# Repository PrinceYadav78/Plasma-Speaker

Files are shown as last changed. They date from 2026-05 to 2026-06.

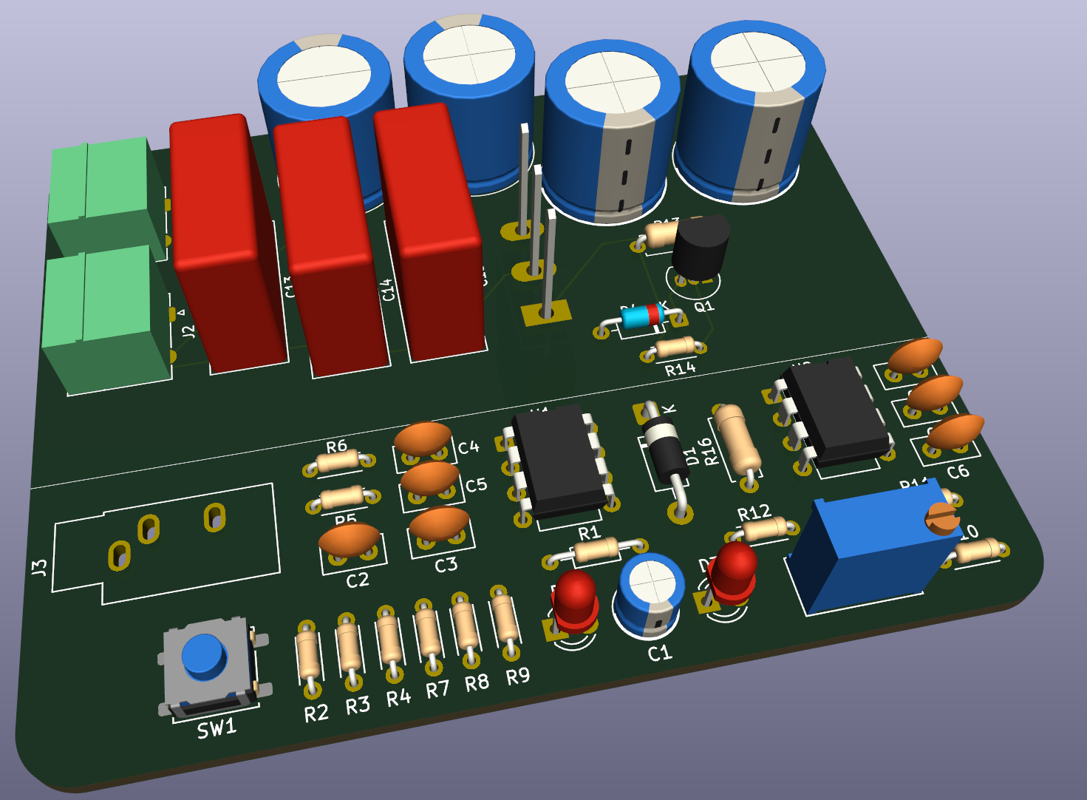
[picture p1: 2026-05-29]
Images/Screenshot 2026-05-18 182442.png

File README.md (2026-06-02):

# Plasma Speaker – PCB Design

so this is my plasma speaker project which i made for my college physics project. basically designed the full circuit and pcb myself from scratch, took around 6 days total. hope it comes out good when i actually build it lol

---

## Why I Did This

honestly it started just as a college physics submission but then i got genuinely interested in how it actually works. plasma speakers are cool because theres no physical cone or membrane, sound comes directly from ionised air through a high voltage arc. felt way more interesting than doing some boring experiment so i decided to design the full electronics myself instead of just buying something readymade

---

## How I Did It

split the whole thing into 4 sections, each one feeds into the next

**DC Input Stage**
started here becuase i wanted stable power before touching anything else. 24v input goes down to 12v using a 1N4742 zener diode with 330ohm 1w resistor. added 100uf smoothing cap and a led indicator. was originally thinking of using 7812 regulator but the heat dissipation at 24v input looked annoying so switched to zener setup. forgot cap polarity once and had to recheck 💀

**Power Switching Stage**
this is the main section, handles high current switching and drives the transformer later. used IRFP260N mosfet becuase cheaper mosfets felt risky after checking other plasma speaker builds. put multiple 470uf 35v caps on the input rail for handling sudden current spikes, started with just one and added more after reading about ripple current. also mixed mkp10 film caps with electrolytics becuase film caps handle high frequency noise better, didnt actually know why people do this before this project 😭. bc327 handles gate drive. routing got messy really fast, almost connected drain and source wrong on the mosfet 💀

**Zero Cross Detector**
built around LM331N with rc filter network using 10n caps. this was genuinly the most confusing part, timing and comparator stuff is more theoretical than power electronics. spent alot of time just reading the datasheet and looking at application circuits. got confused between feedback path and threshold pin like 3 times. still not fully sure it will behave exactly how i want until i test it on oscilloscope honestly

**Oscillator**
NE555 in astable mode. choosed 555 becuase its simple and well documented, didnt want to deal with complicated pwm ic on top of everything else. 10n and 4.7n timing caps with 5k pot for manual frequency adjustment because transformer resonance can vary and i wanted tuning option during testing. almost connected discharge pin wrong aswell 💀 led indicator added to atleast visually confirm its running

---

## PCB Design

did this in kicad didnt really have a big plan going in, just placed things with few things in mind

- terminal connectors and aux stuff on one side, big caps on the other side
- power section components as close as possible to keep traces short
- mosfet placed face down so i can attach aluminium block behind for cooling
- lm331 and ne555 grouped together on bottom half of board
- copper zones filled on both layers for cooling and reducing noise

did silkscreen on both front and back copper layers, took quite some time but looks nice. only real rule i followed was keep connections short and make it look atleast a little symmetric

---

## Components

sourced everything from mouser, made full bom and verified all parts. cart is ready

---

## Build Log

| Day | What I did | Time |
|-----|---|---|
| 1 | DC input stage schematic | 30min |
| 2 | Power switching stage schematic | 2hr 30min |
| 3 | Zero cross detector schematic | 3hr |
| 4 | Oscillator schematic | 2hr 45min |
| 5 | Full PCB routing and silkscreen | 4hr 30min |
| 6 | BOM and mouser sourcing and later cost cutting by switching to digikey | 1hr 30 min|

---

## Schematic



---

## PCB








---

## Cart










---

## BOM

| Index | Qty | Part Number | Manufacturer Part Number | Description | Available | Backorder | Unit Price | Extended Price INR |
|---:|----:|---|---|---|---:|---:|---:|---:|
| 1 | 10 | 2.2KEBK-ND | CFR-12JB-52-2K2 | RES 2.2K OHM 5% 1/6W AXIAL | 10 | 0 | 3.727 | ₹37.27 |
| 2 | 25 | 1.0KEBK-ND | CFR-12JB-52-1K | RES 1K OHM 5% 1/6W AXIAL | 25 | 0 | 3.0936 | ₹77.34 |
| 3 | 10 | 470EBK-ND | CFR-12JB-52-470R | RES 470 OHM 5% 1/6W AXIAL | 10 | 0 | 3.727 | ₹37.27 |
| 4 | 10 | 100EBK-ND | CFR-12JB-52-100R | RES 100 OHM 5% 1/6W AXIAL | 10 | 0 | 3.448 | ₹34.48 |
| 5 | 10 | 10KEBK-ND | CFR-12JB-52-10K | RES 10K OHM 5% 1/6W AXIAL | 10 | 0 | 3.634 | ₹36.34 |
| 6 | 10 | 220EBK-ND | CFR-12JB-52-220R | RES 220 OHM 5% 1/6W AXIAL | 10 | 0 | 3.727 | ₹37.27 |
| 7 | 10 | 33KEBK-ND | CFR-12JB-52-33K | RES 33K OHM 5% 1/6W AXIAL | 10 | 0 | 3.448 | ₹34.48 |
| 8 | 10 | 3.3KEBK-ND | CFR-12JB-52-3K3 | RES 3.3K OHM 5% 1/6W AXIAL | 10 | 0 | 3.448 | ₹34.48 |
| 9 | 10 | 399-6601-ND | ESK107M016AC3AA | CAP ALUM 100UF 20% 16V RADIAL TH | 10 | 0 | 10.064 | ₹100.64 |
| 10 | 10 | 445-8348-ND | FK16X7R1C106KR020 | CAP CER 10UF 16V X7R RADIAL | 10 | 0 | 28.235 | ₹282.35 |
| 11 | 10 | 445-180204-ND | FG18X7R1E105KRT00 | CAP CER 1UF 25V X7R RADIAL | 10 | 0 | 16.96 | ₹169.60 |
| 12 | 20 | 399-6086-ND | ESC477M035AH4AA | CAP ALUM 470UF 20% 35V RADIAL TH | 20 | 0 | 37.74 | ₹754.80 |
| 13 | 2 | IRFP260NPBF-ND | IRFP260NPBF | MOSFET N-CH 200V 50A TO247AC | 2 | 0 | 587.07 | ₹1,174.14 |
| 14 | 10 | WP710A10PGT-ND | WP710A10PGT | LED GREEN CLEAR T-1 T/H | 10 | 0 | 17.426 | ₹174.26 |
| 15 | 10 | 754-1606-ND | WP710A10ID | LED RED DIFFUSED T-1 T/H | 10 | 0 | 14.071 | ₹140.71 |
| 16 | 5 | CKN12301-ND | PTS636SL43 LFS | SWITCH TACTILE SPST-NO 0.05A 12V | 5 | 0 | 15.84 | ₹79.20 |
| 17 | 5 | 3296W-1-252LF-ND | 3296W-1-252LF | TRIMMER 2.5K OHM 0.5W PC PIN TOP | 5 | 0 | 224.58 | ₹1,122.90 |
| 18 | 10 | 13-CFR-25JR-52-270RCT-ND | CFR-25JR-52-270R | RES 270 OHM 5% 1/4W AXIAL | 10 | 0 | 3.262 | ₹32.62 |
| 19 | 10 | 330WCT-ND | FMP100JR-52-330R | RES 330 OHM 5% 1W AXIAL | 10 | 0 | 7.921 | ₹79.21 |
| 20 | 15 | 445-173264-1-ND | FG18X7R1H103KNT06 | CAP CER 10000PF 50V X7R RADIAL | 15 | 0 | 12.021 | ₹180.32 |
| 21 | 10 | 445-173265-1-ND | FG18X7R1H104KNT06 | CAP CER 0.1UF 50V X7R RADIAL | 10 | 0 | 12.953 | ₹129.53 |
| 22 | 10 | 445-173598-1-ND | FG28X7R1H472KNT06 | CAP CER 4700PF 50V X7R RADIAL | 10 | 0 | 12.021 | ₹120.21 |
| 23 | 15 | 1928-MKP1G031004D00KSSD-ND | MKP1G031004D00KSSD | MKP 10 0.1F 400V DC 7X14X18 PCM | 0 | 15 | 54.793 | ₹821.90 |
| 24 | 10 | 4878-BC327-40BK-ND | BC327-40BK | TRANS PNP 45V 0.8A TO-92 | 10 | 0 | 10.157 | ₹101.57 |
| 25 | 5 | LM311NNS/NOPB-ND | LM311N/NOPB | IC COMPARATOR 1 GEN PUR 8DIP | 5 | 0 | 85.73 | ₹428.65 |
| 26 | 5 | LM311NNS/NOPB-ND | LM311N/NOPB | IC COMPARATOR 1 GEN PUR 8DIP | 5 | 0 | 85.73 | ₹428.65 |
| 27 | 10 | 1N4742A-T50ACT-ND | 1N4742A-T50A | DIODE ZENER 12V 1W DO41 | 10 | 0 | 15.842 | ₹158.42 |
| 28 | 10 | 1N4148FS-ND | 1N4148 | DIODE STANDARD 100V 200MA DO35 | 10 | 0 | 5.125 | ₹51.25 |
| 29 | 10 | 102-6203-ND | TB007-508-02BE | TERMINAL BLOCK, SCREW TYPE, 5.08 | 10 | 0 | 36.995 | ₹369.95 |
| 30 | 5 | SC1852-ND | PJRAN1X1U01AUX | CONN RCA JACK MONO 3.2MM R/A | 5 | 0 | 275.83 | ₹1,379.15 |
| 31 | 1 | Power (Own Funded) | - | - | 1 | 0 | 3999 | ₹0 |
| 32 | 2 | Transformer (Own Funded) | - | - | 2 | 0 | 499 | ₹0 |
| 33 | 1 | PCB | - | - | 1 | 0 | 989 | ₹989 |
| | | | | **TOTAL** | | | | **₹9,597.96** |

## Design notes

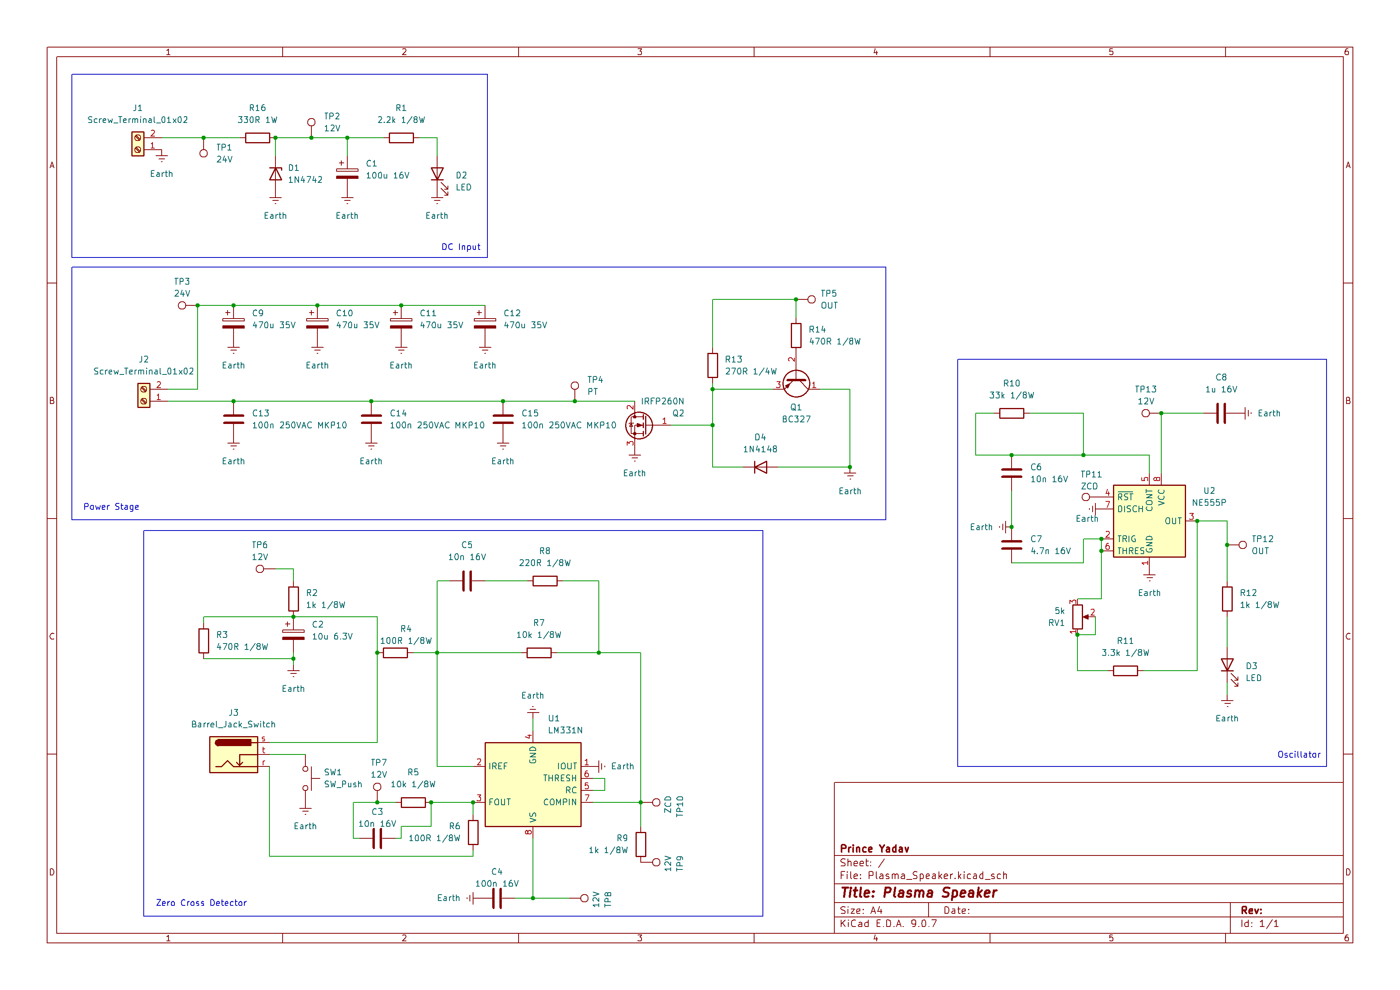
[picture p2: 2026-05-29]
Images/Schematic.png

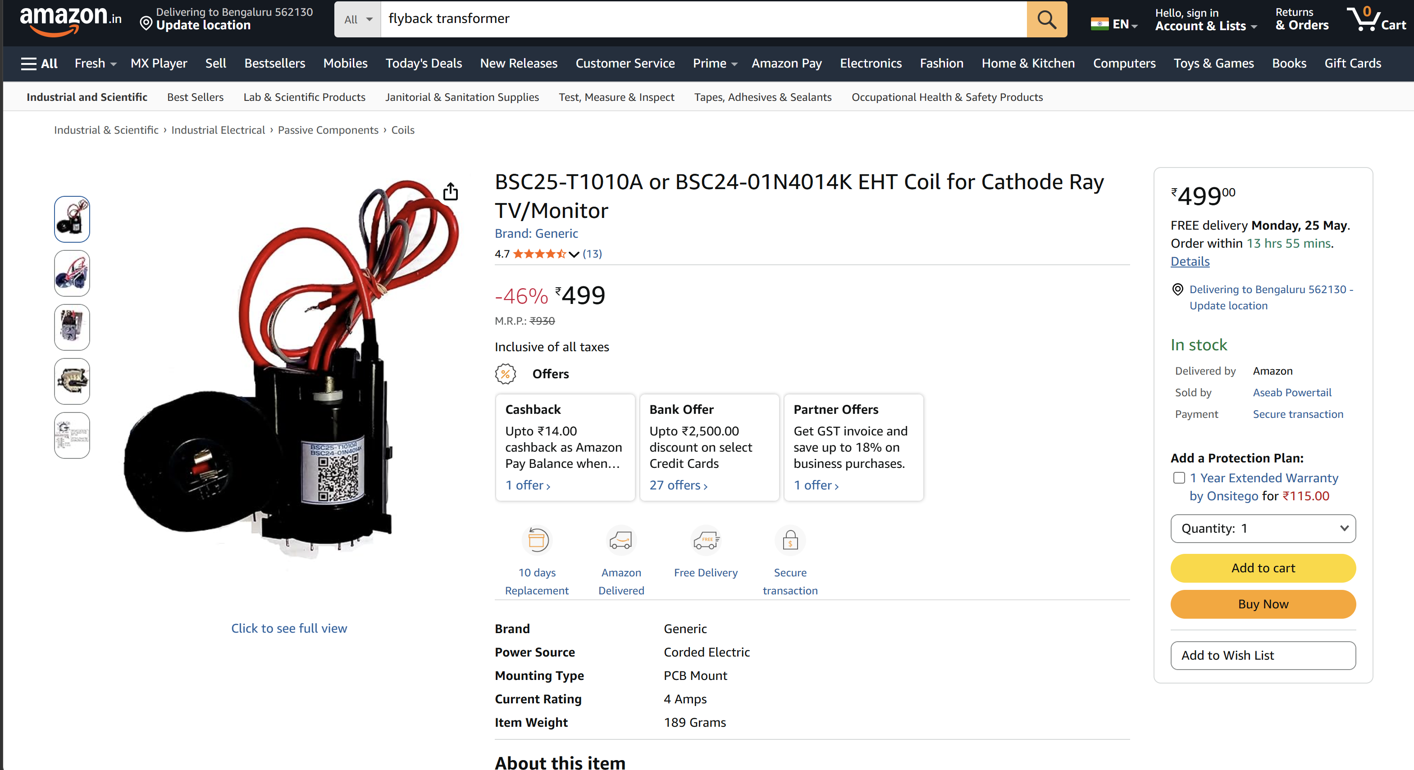
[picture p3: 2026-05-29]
Images/Screenshot 2026-05-18 190657.png

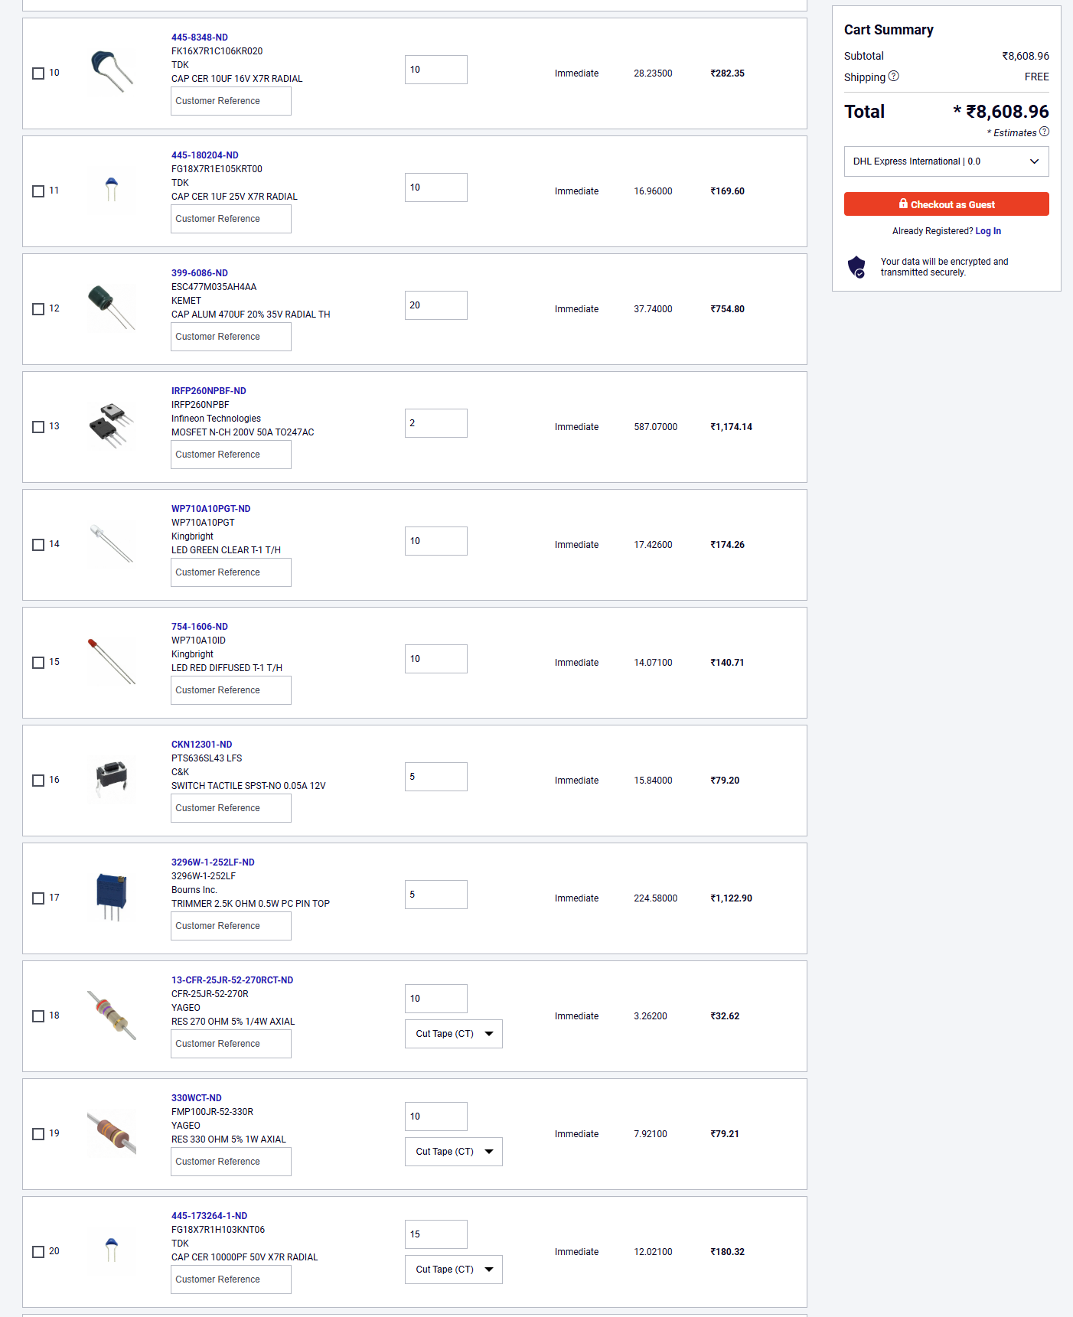
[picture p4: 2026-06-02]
Images/Screenshot 2026-06-02 192737.png

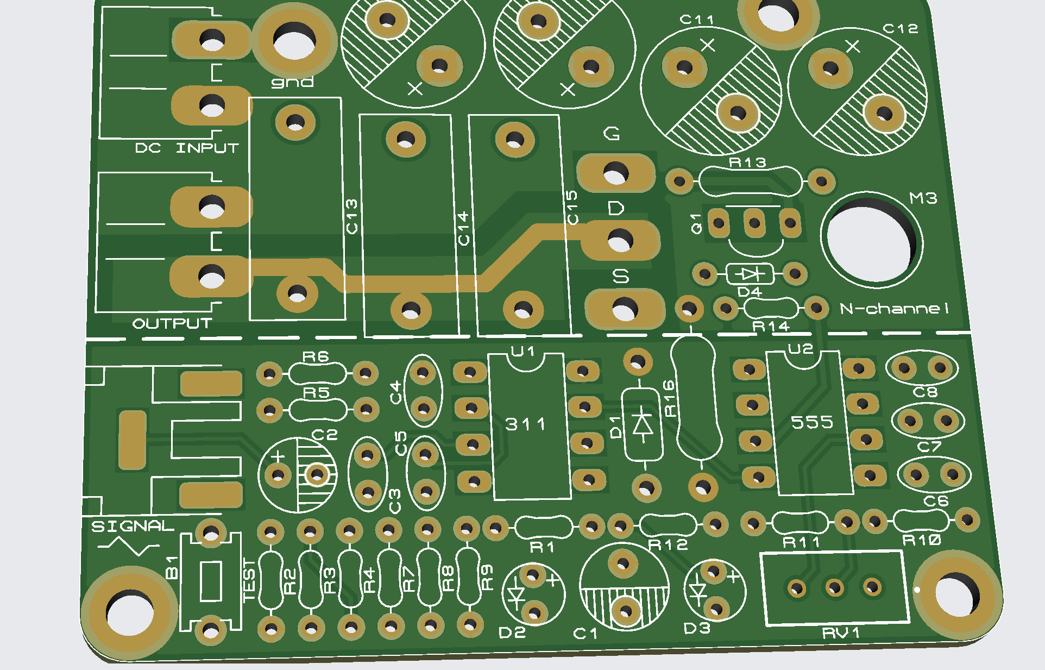
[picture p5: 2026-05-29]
Images/Screenshot 2026-05-18 182231.png

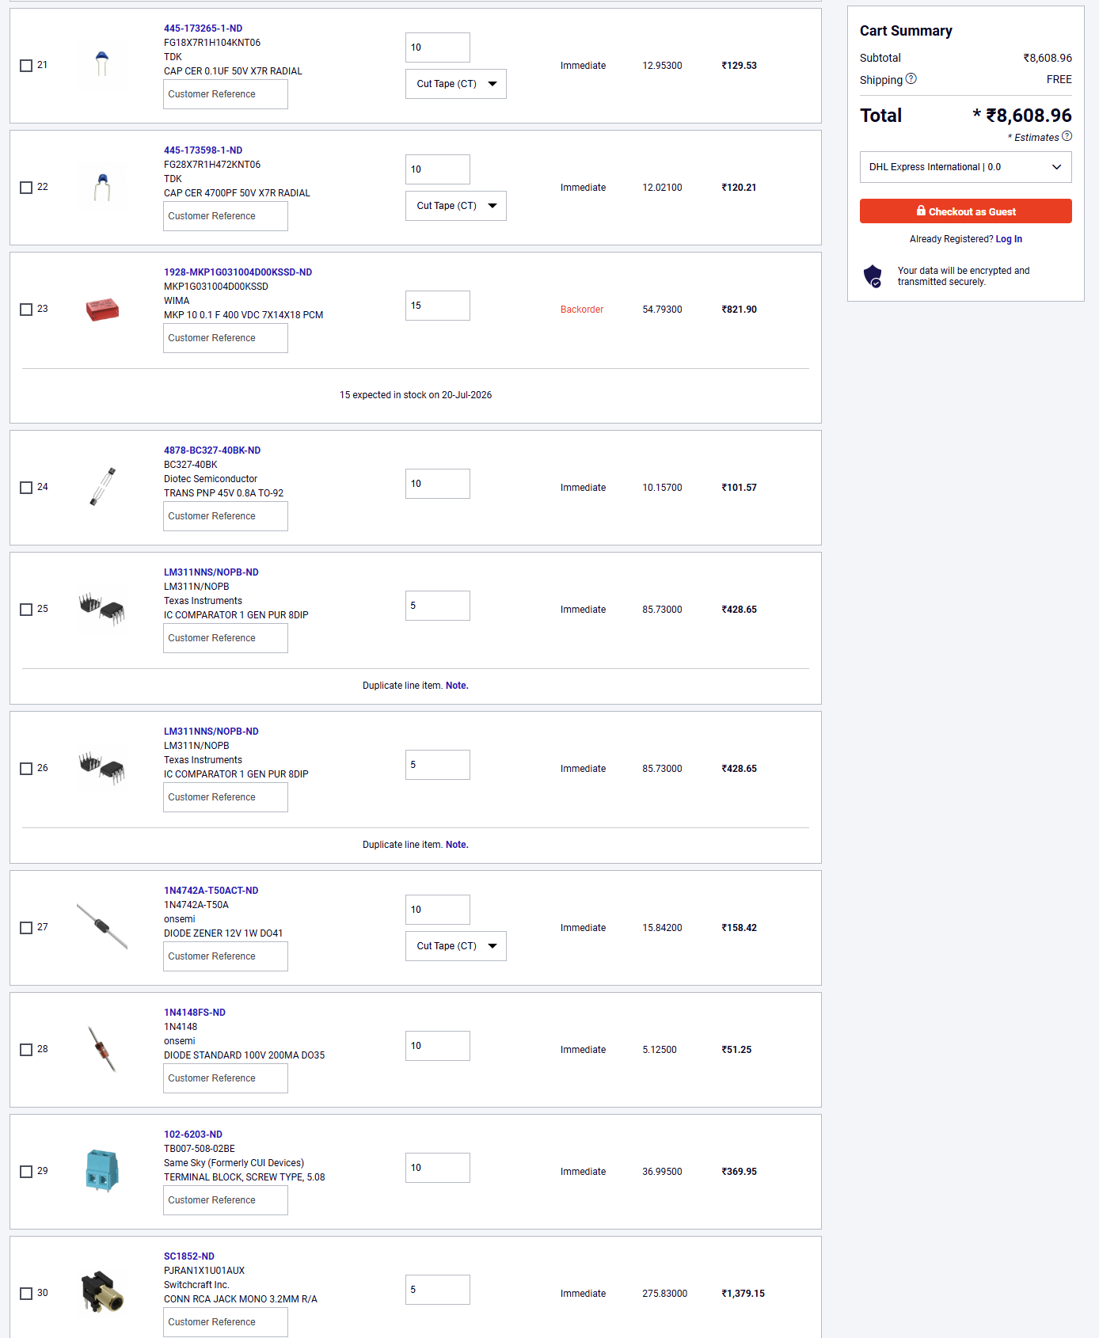
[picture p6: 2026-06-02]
Images/Screenshot 2026-06-02 192749.png

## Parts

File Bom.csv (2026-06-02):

Index | Quantity | Part Number | Manufacturer Part Number | Description | Link | Available | Backorder | Unit Price | Extended Price INR
1 | 10 | 2.2KEBK-ND | CFR-12JB-52-2K2 | RES 2.2K OHM 5% 1/6W AXIAL | https://www.digikey.in/en/products/detail/yageo/CFR-12JB-52-2K2/3992 | 10 | 0 | 3.727 | ₹37.27
2 | 25 | 1.0KEBK-ND | CFR-12JB-52-1K | RES 1K OHM 5% 1/6W AXIAL | https://www.digikey.in/en/products/detail/yageo/CFR-12JB-52-1K/4000 | 25 | 0 | 3.0936 | ₹77.34
3 | 10 | 470EBK-ND | CFR-12JB-52-470R | RES 470 OHM 5% 1/6W AXIAL | https://www.digikey.in/en/products/detail/yageo/CFR-12JB-52-470R/4005 | 10 | 0 | 3.727 | ₹37.27
4 | 10 | 100EBK-ND | CFR-12JB-52-100R | RES 100 OHM 5% 1/6W AXIAL | https://www.digikey.in/en/products/detail/yageo/CFR-12JB-52-100R/4019 | 10 | 0 | 3.448 | ₹34.48
5 | 10 | 10KEBK-ND | CFR-12JB-52-10K | RES 10K OHM 5% 1/6W AXIAL | https://www.digikey.in/en/products/detail/yageo/CFR-12JB-52-10K/3977 | 10 | 0 | 3.634 | ₹36.34
6 | 10 | 220EBK-ND | CFR-12JB-52-220R | RES 220 OHM 5% 1/6W AXIAL | https://www.digikey.in/en/products/detail/yageo/CFR-12JB-52-220R/4013 | 10 | 0 | 3.727 | ₹37.27
7 | 10 | 33KEBK-ND | CFR-12JB-52-33K | RES 33K OHM 5% 1/6W AXIAL | https://www.digikey.in/en/products/detail/yageo/CFR-12JB-52-33K/3962 | 10 | 0 | 3.448 | ₹34.48
8 | 10 | 3.3KEBK-ND | CFR-12JB-52-3K3 | RES 3.3K OHM 5% 1/6W AXIAL | https://www.digikey.in/en/products/detail/yageo/CFR-12JB-52-3K3/3989 | 10 | 0 | 3.448 | ₹34.48
9 | 10 | 399-6601-ND | ESK107M016AC3AA | CAP ALUM 100UF 20% 16V RADIAL TH | https://www.digikey.in/en/products/detail/yageo/CFR-25JR-52-270R/11960 | 10 | 0 | 10.064 | ₹100.64
10 | 10 | 445-8348-ND | FK16X7R1C106KR020 | CAP CER 10UF 16V X7R RADIAL | https://www.digikey.in/en/products/detail/yageo/FMP100JR-52-330R/2058601 | 10 | 0 | 28.235 | ₹282.35
11 | 10 | 445-180204-ND | FG18X7R1E105KRT00 | CAP CER 1UF 25V X7R RADIAL | https://www.digikey.in/en/products/detail/kemet/ESK107M016AC3AA/3083016 | 10 | 0 | 16.96 | ₹169.60
12 | 20 | 399-6086-ND | ESC477M035AH4AA | CAP ALUM 470UF 20% 35V RADIAL TH | https://www.digikey.in/en/products/detail/tdk/FK16X7R1C106KR020/2815278 | 20 | 0 | 37.74 | ₹754.80
13 | 2 | IRFP260NPBF-ND | IRFP260NPBF | MOSFET N-CH 200V 50A TO247AC | https://www.digikey.in/en/products/detail/tdk/FG18X7R1H103KNT06/5802878 | 2 | 0 | 587.07 | ₹1,174.14
14 | 10 | WP710A10PGT-ND | WP710A10PGT | LED GREEN CLEAR T-1 T/H | https://www.digikey.in/en/products/detail/tdk/FG18X7R1H104KNT06/5802879 | 10 | 0 | 17.426 | ₹174.26
15 | 10 | 754-1606-ND | WP710A10ID | LED RED DIFFUSED T-1 T/H | https://www.digikey.in/en/products/detail/tdk/FG28X7R1H472KNT06/5803212 | 10 | 0 | 14.071 | ₹140.71
16 | 5 | CKN12301-ND | PTS636SL43 LFS | SWITCH TACTILE SPST-NO 0.05A 12V | https://www.digikey.in/en/products/detail/tdk/FG18X7R1E105KRT00/7326658 | 5 | 0 | 15.84 | ₹79.20
17 | 5 | 3296W-1-252LF-ND | 3296W-1-252LF | TRIMMER 2.5K OHM 0.5W PC PIN TOP | https://www.digikey.in/en/products/detail/kemet/ESC477M035AH4AA/2712516 | 5 | 0 | 224.58 | ₹1,122.90
18 | 10 | 13-CFR-25JR-52-270RCT-ND | CFR-25JR-52-270R | RES 270 OHM 5% 1/4W AXIAL | https://www.digikey.in/en/products/detail/wima/mkp1g031004d00kssd/19251065 | 10 | 0 | 3.262 | ₹32.62
19 | 10 | 330WCT-ND | FMP100JR-52-330R | RES 330 OHM 5% 1W AXIAL | https://www.digikey.in/en/products/detail/diotec-semiconductor/bc327-40bk/13154014 | 10 | 0 | 7.921 | ₹79.21
20 | 15 | 445-173264-1-ND | FG18X7R1H103KNT06 | CAP CER 10000PF 50V X7R RADIAL | https://www.digikey.in/en/products/detail/infineon-technologies/irfp260npbf/811623 | 15 | 0 | 12.021 | ₹180.32
21 | 10 | 445-173265-1-ND | FG18X7R1H104KNT06 | CAP CER 0.1UF 50V X7R RADIAL | https://www.digikey.in/en/products/detail/texas-instruments/LM311N-NOPB/6175 | 10 | 0 | 12.953 | ₹129.53
22 | 10 | 445-173598-1-ND | FG28X7R1H472KNT06 | CAP CER 4700PF 50V X7R RADIAL | https://www.digikey.in/en/products/detail/texas-instruments/NE555P/277057 | 10 | 0 | 12.021 | ₹120.21
23 | 15 | 1928-MKP1G031004D00KSSD-ND | MKP1G031004D00KSSD | MKP 10 0.1 F 400 VDC 7X14X18 PCM | https://www.digikey.in/en/products/detail/onsemi/1N4742A-T50A/977259 | 0 | 15 | 54.793 | ₹821.90
24 | 10 | 4878-BC327-40BK-ND | BC327-40BK | TRANS PNP 45V 0.8A TO-92 | https://www.digikey.in/en/products/detail/kingbright/wp710a10pgt/3084194 | 10 | 0 | 10.157 | ₹101.57
25 | 5 | LM311NNS/NOPB-ND | LM311N/NOPB | IC COMPARATOR 1 GEN PUR 8DIP | https://www.digikey.in/en/products/detail/kingbright/WP710A10ID/2769809 | 5 | 0 | 85.73 | ₹428.65
26 | 5 | LM311NNS/NOPB-ND | LM311N/NOPB | IC COMPARATOR 1 GEN PUR 8DIP | https://www.digikey.in/en/products/detail/onsemi/1N4148/458603 | 5 | 0 | 85.73 | ₹428.65
27 | 10 | 1N4742A-T50ACT-ND | 1N4742A-T50A | DIODE ZENER 12V 1W DO41 | https://www.digikey.in/en/products/detail/c-k/PTS636SL43-LFS/10071714 | 10 | 0 | 15.842 | ₹158.42
28 | 10 | 1N4148FS-ND | 1N4148 | DIODE STANDARD 100V 200MA DO35 | https://www.digikey.in/en/products/detail/same-sky-formerly-cui-devices/tb007-508-02be/10064127 | 10 | 0 | 5.125 | ₹51.25
29 | 10 | 102-6203-ND | TB007-508-02BE | TERMINAL BLOCK, SCREW TYPE, 5.08 | https://www.digikey.in/en/products/detail/bourns-inc/3296w-1-252lf/2535912 | 10 | 0 | 36.995 | ₹369.95
30 | 5 | SC1852-ND | PJRAN1X1U01AUX | CONN RCA JACK MONO 3.2MM R/A | https://www.digikey.in/en/products/detail/switchcraft-inc/PJRAN1X1U01AUX/1288659 | 5 | 0 | 275.83 | ₹1,379.15
31 | 1 | Power ( Own Funded ) |  |  | https://www.electropi.in/24v-30amp-smps-720w-dc-metal-power-supply-nwp-india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 | 1 | 0 | 3999 | ₹0
32 | 2 | Transformer ( Own Funded ) |  |  | https://amzn.in/d/0g0eCBQw | 2 | 0 | 499 | ₹0
33 | 1 | PCB |  |  | JLCPCB | 1 | 0 | 989 | ₹989
 |  |  |  |  |  |  |  | Total | ₹9579.96 ($100)

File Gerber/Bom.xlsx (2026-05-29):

Quantity | References | Value | Code | Link | Cost | Total
5 | R1 | 2.2k | CFR-12JB-52-2K2 | CFR-12JB-52-2K2 YAGEO | Mouser India (https://www.mouser.in/ProductDetail/YAGEO/CFR-12JB-52-2K2) | ₹18.64 | ₹93.20
15 | R2,R9,R12 | 1k | CFR-12JB-52-1K | CFR-12JB-52-1K YAGEO | Mouser (https://www.mouser.com/ProductDetail/YAGEO/CFR-12JB-52-1K?qs=8uyp%2Fy7yFW6RQpJpptx%2FjA%3D%3D) | ₹8.39 | ₹125.85
10 | R3,R14 | 470R | CFR-12JB-52-470R | CFR-12JB-52-470R YAGEO | Mouser India (https://www.mouser.in/ProductDetail/YAGEO/CFR-12JB-52-470R) | ₹8.39 | ₹83.90
10 | R4,R6 | 100R | CFR-12JB-52-100R | CFR-12JB-52-100R YAGEO | Mouser India (https://www.mouser.in/ProductDetail/YAGEO/CFR-12JB-52-100R) | ₹8.39 | ₹83.90
10 | R5,R7 | 10k | CFR-12JB-52-10K | CFR-12JB-52-10K YAGEO | Mouser India (https://www.mouser.in/ProductDetail/YAGEO/CFR-12JB-52-10K) | ₹8.39 | ₹83.90
5 | R8 | 220R | CFR-12JB-52-220R | CFR-12JB-52-220R YAGEO | Mouser India (https://www.mouser.in/ProductDetail/YAGEO/CFR-12JB-52-220R) | ₹18.64 | ₹93.20
5 | R10 | 33k | CFR-12JB-52-33K | CFR-12JB-52-33K YAGEO | Mouser India (https://www.mouser.in/ProductDetail/YAGEO/CFR-12JB-52-33K) | ₹18.64 | ₹93.20
5 | R11 | 3.3k | CFR-12JB-52-3K3 | CFR-12JB-52-3K3 YAGEO | Mouser India (https://www.mouser.in/ProductDetail/YAGEO/CFR-12JB-52-3K3) | ₹18.64 | ₹93.20
5 | R13 | 270R | CFR-25JR-52-270R | CFR-25JR-52-270R YAGEO | Mouser India (https://www.mouser.in/ProductDetail/YAGEO/CFR-25JR-52-270R) | ₹9.32 | ₹46.60
5 | R16 | 330R | FMP100JR-52-330R | FMP100JR-52-330R YAGEO | Mouser India (https://www.mouser.in/ProductDetail/YAGEO/FMP100JR-52-330R) | ₹12.11 | ₹60.55
5 | C1 | 100u | ESK107M016AC3AA | ESK107M016AC3AA KEMET | Mouser India (https://www.mouser.in/ProductDetail/KEMET/ESK107M016AC3AA?qs=9RUIYXQlAdBlfkFfvuUkxQ%3D%3D) | ₹17.70 | ₹88.50
5 | C2 | 10u | FK16X7R1C106K | FK16X7R1C106K TDK | Mouser India (https://www.mouser.in/ProductDetail/TDK/FK16X7R1C106K?qs=sGAEpiMZZMvsSlwiRhF8qk5dk0Ff3GLt7CBGZPfzGBA%3D) | ₹46.59 | ₹232.95
15 | C3,C5,C6 | 10n | FG18X7R1H103KNT06 | FG18X7R1H103KNT06 TDK | Mouser India (https://www.mouser.in/ProductDetail/TDK/FG18X7R1H103KNT06) | ₹8.67 | ₹130.05
5 | C4 | 100n | FG18X7R1H104KNT06 | FG18X7R1H104KNT06 TDK | Mouser India (https://www.mouser.in/ProductDetail/TDK/FG18X7R1H104KNT06?qs=qf2ddTMq67WA8sH6FratLA%3D%3D) | ₹22.36 | ₹111.80
5 | C7 | 4.7n | FG28X7R1H472KNT06 | FG28X7R1H472KNT06 TDK | Mouser India (https://www.mouser.in/ProductDetail/TDK/FG28X7R1H472KNT06?qs=qf2ddTMq67VHPU0W%252B3I8vg%3D%3D) | ₹20.50 | ₹102.50
5 | C8 | 1u | FG18X7R1E105KRT00 | FG18X7R1E105KRT00 TDK | Mouser India (https://www.mouser.in/ProductDetail/TDK/FG18X7R1E105KRT00?qs=vNwBHymccZ%252B2%252BCnL09vDMw%3D%3D) | ₹28.89 | ₹144.45
20 | C9,C10,C11,C12 | 470u | ESC477M035AH4AA | ESH477M035AL3AA KEMET | Mouser India (https://www.mouser.in/ProductDetail/KEMET/ESH477M035AL3AA) | ₹34.85 | ₹697.00
15 | C13,C14,C15 | 100n | MKP10-.1/400/5P15 | MKP10-.1/400/5P15 WIMA | Mouser India (https://www.mouser.in/ProductDetail/WIMA/MKP10-1-400-5P15?qs=ruR7qzrNb6g3VgX%252BWvHiGQ%3D%3D) | ₹54.23 | ₹813.45
5 | Q1 | BC327 | BC327-40-AP | BC327-40 Diotec Semiconductor | Mouser India (https://www.mouser.in/ProductDetail/Diotec-Semiconductor/BC327-40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) | ₹15.84 | ₹79.20
5 | Q2 | IRFP260N | IRFP260NPBF | IRFP260NPBF Infineon Technologies | Mouser India (https://www.mouser.in/ProductDetail/Infineon-Technologies/IRFP260NPBF?qs=9%252BKlkBgLFf2Q0aoG2Yfqfg%3D%3D) | ₹498.51 | ₹2492.55
5 | U1 | LM311N | LM311N/NOPB | LM311N/NOPB Texas Instruments | Mouser India (https://www.mouser.in/ProductDetail/Texas-Instruments/LM311N-NOPB?qs=X1J7HmVL2ZEW%2F3U%252B2FkA%2Fw%3D%3D) | ₹85.73 | ₹428.65
5 | U2 | NE555N | NE555PE4 | NE555PE4 Texas Instruments | Mouser India (https://www.mouser.in/ProductDetail/Texas-Instruments/NE555PE4?qs=rLYyFdxB%2FmpV6UJXAtWXuA%3D%3D) | ₹109.02 | ₹545.10
5 | D1 | 1N4742 | 1N4742A-T50A | 1N4742A-T50A onsemi | Mouser India (https://www.mouser.in/ProductDetail/onsemi/1N4742A-T50A?qs=0lQeLiL1qyaUl85kww6yHQ%3D%3D) | ₹26.09 | ₹130.45
5 | D2 | GREEN | WP710A10PGT | WP710A10PGT Kingbright | Mouser India (https://www.mouser.in/ProductDetail/Kingbright/WP710A10PGT?qs=jBF9H7RTBaQqx0iDNHF17A%3D%3D) | ₹25.16 | ₹125.80
5 | D3 | RED | WP710A10ID | WP710A10ID Kingbright | Mouser India (https://www.mouser.in/ProductDetail/Kingbright/WP710A10ID?qs=wRBQ8ZgBZ98VyHeNIlWGkQ%3D%3D) | ₹20.50 | ₹102.50
5 | D4 | 1N4148 | 1N4148 | 1N4148 onsemi | Mouser India (https://www.mouser.in/ProductDetail/onsemi/1N4148?qs=i4Fj9T%2FoRm8RMUhj5DeFQg%3D%3D) | ₹9.32 | ₹46.60
5 | B1 | BUTTON | PTS636SL43 LFS | PTS636SL43 LFS C&K | Mouser India (https://www.mouser.in/ProductDetail/CK/PTS636SL43-LFS?qs=jcD%2FCkGBYeOwjxNXDGvRDg%3D%3D) | ₹13.98 | ₹69.90
10 | DC | INPUT,OUTPUT | CONN2-200 | TB007-508-02BE Same Sky | Mouser India (https://www.mouser.in/ProductDetail/Same-Sky/TB007-508-02BE) | ₹35.78 | ₹357.80
5 | RV1 | 5k | 3296W-1-252LF | 3296W-1-252LF Bourns | Mouser India (https://www.mouser.in/ProductDetail/Bourns/3296W-1-252LF?qs=VW5eOWd7Luy89Xw%2FKwu%2Fxg%3D%3D) | ₹218.97 | ₹1094.85
5 | SIGNAL | RCA-JACK | PJRAN1X1U02AUX | PJRAN1X1U02AUX Switchcraft | Mouser India (https://www.mouser.in/ProductDetail/Switchcraft/PJRAN1X1U02AUX?qs=mcPJWgAPNrfnzxVPOaEt1A%3D%3D) | ₹277.68 | ₹1388.40
1 | Power | 24V 30A |  | SMPS (https://www.electropi.in/24v-30amp-smps-720w-dc-metal-power-supply-nwp-india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) | ₹3999.00 | ₹3999.00
2 | Transformer | Flyback | BSC25-T1010A | Flyback (https://amzn.in/d/0g0eCBQw) | ₹499.00 | ₹998.00
5 | PCB |  |  |  | ₹989.00 | ₹989.00
 |  |  |  |  | Shipping | ₹1200.00
 |  |  |  |  | Total (INR) | ₹17226.00
 |  |  |  |  | Total (USD) | $172.26

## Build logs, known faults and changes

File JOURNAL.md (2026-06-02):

---
Title: “Plasma Speaker”
Author: “Prince Yadav”
Description: “A cool Speaker without a speaker for my physcis project in college”
Created_At: “2026-05-24”
---

# May 24: Schematic Layout for Input – speaker very sentive to input as arc length depends on it
started with dc input stage first becuase i wanted stable power before touching anything else. using 24v input and making 12v rail using zener diode, initially was thinking of using 7812 regulator but then realised with 24v input the heat dissipation would become annoying so switched the plan midway
used 1N4742 zener for 12v becuase it was available and simple enough. selected 330 ohm 1 watt resistor after calculating dissipation, almost used lower watt resistor without checking properly which couldve ended bad later. added 100uf 16v cap for smoothing, was confused between 100uf and 220uf for sometime but finally went with 100uf to keep things smaller and less bulky
led indicator with 2.2k resistor added because debugging without power indication is honestly painfull. kept test points for both 24v and 12v rails for easier probing later
forgot capacitor polarity once 💀 had to recheck , looked simple in starting but somehow still took more time than expected honestly uk bcz of that multiple point 24v and 12v which I needed claude help also
 

**Total time Spent: 30min (8:30pm to 9:00pm)**

# May 25: Schematic Layout for Flyback – also very important bcz there could be prev. power surges
worked on main power switching stage today. this part felt way more serious because its handling higher current and later driving the transformer. went with IRFP260N mosfet, cheaper mosfets felt little risky for this project bcz if the gate discharges too slowly, the mosfet stays its linear region long, get hot, and burn out.
added multiple 470uf 35v caps on input side because plasma load can pull sudden spikes and i didnt want supply rail drooping random. started with just one cap and later added more after reading about ripple current handling on claude. 35v rating choosen because input is 24v and wanted enough safety margin
used mkp10 film caps near switching side alongside electrolytics. honestly before this i didnt even know why people mix capacitor types ,later understood film caps handle high frequency switching noise much better with the help of claude 😊claude told: You cannot use normal ceramic or electrolytic caps here because they would overheat from the high-frequency AC currents 
bc327 transistor used for gate drive and diode for discharge path. routing became mess,almost connected drain and source wrong on mosfet and had to recheck pinout like twice 💀 bcz I started fully clumsy but later made it expanded.


**Note: Used claude to know about electronics and not guide with sch.. sch made based on instincts and datasheets**
 
**Total time Spent: 2hr 30min (6:00pm to 8:30pm)**

# May 26: Schematic Layout for Tunning – boss level for me

worked on zero cross detector section using LM331N (strict mathematical formulas provided by texas instruments – very stupid I feel but ok). this part was genuinly confusing, comparator and timing stuff always feels more theoretical compared to power electronics 😭 spent lot of time just reading datasheet and ate half of claude’s brain
used rc network with 10n capacitors and resistor combinations for filtering. had different values initially but timing response looked unstable (based on claude) so changed few values after experimenting little bit with claude. added decoupling cap near supply because these ic’s can behave weird if supply gets noisy especially with switching section nearby 10k and 1k resistors mainly for biasing and feedback control. got confused between output feedback path and threshold path at one on LM331. rechecked pinout maybe 3 times because datasheet diagram was looking cursed honestly 💀barrel jack and push switch added for easier testing and manual triggering. test points kept throughout becuase probing signals on crowded pcb without them becomes nightmare, already learnt that from previous stages
still not fully sure LM331 will behave exactly how i want until i verify after building it just bcz of few stupid maths


**Total time Spent: 3hr (9:00pm to 12:00am) – very tiring to do after college**

# May 27: Schematic Layout for oscillation

worked on oscillator section using NE555. choosed 555 because its simple reliable and well documented, didnt want to deal with some complicated pwm controller on top of everything else. used 10n and 4.7n caps with resistor network around the 555 for oscillation frequency. picked values after checking calculations 0061nd. potentiometer added for frequency adjustment because transformer resonance can vary alot and i wanted manual tuning option during testing
I also added led output indicator again because seeing oscillator actually running makes debugging easier. also added test points at output and zcd signal lines too also added decoupling capacitor on supply because hv switching noise nearby could affect oscillator stability. not much else honestly, 555 becomes pretty straightforward once you stop second guessing every pin connection . 


And now finally finished the full sch.. including assigning footprints…


**Total time Spent: 2hr 45min (8:00pm to 10:45pm) **

# May 28 – PCB Routing – It was a holiday in my school so free full day 😊
Started with PCB Routing – Fully mind no planning did just wt ever came to my mind so specific reasons for doing anything


Made a rectangle with rough estimate and then made fillet lines (3mm) – just a number which came to my mind


So now my plan is keep the terminal box and aux towards one side of the pcb and the big capacitor towards the right 


Now I place to finish the power section by placing those big rectangle components as near as possible and keeping the traces small and also I would like to keep the mosfet faced down u know for better cooling so that I can attach a aluminium block behind it


 Now post this I would like to continue with the bottom half of the board where both u1 and u2 I would like to place


Yeah so now I places everthing the only rule I followed was closed connection and u know a bit symmetry which make the board looks good.
Now its time for the wiring.


Only F.Cu this is and did some very nicr f.silkscreen work 

 
And this is only B.cu with back silkscreen here also some very tedious work I did 
Now it time to fill these thing with copper zone uk for cooling purpose also and also for less disturbance



Yeah so now my PCB routing and silkscreen work is also done successfully
3D pic of my design:



**Total time Spent: 4hr 30min (11:00am to 12:30pm – Then lunch break – from 1:30pm to 3:30pm) **

# May 28 – BOM making and selecting exact parts
Figured out all components in Mouser and made the bom fully and attached all cart photos.. 









The most tedious job was to take care that in this project components could heat up and fail so selecting parts take time.. also for justifying the time u can see the bom quality
Final message – This project is for my Physics project in my college … I hope it comes out good

**Total time Spent: 1hr (9:00pm to 10:00pm)**

# June 2 – Cost Cutting

Did the cost cutting by swittching to digikey.. and funding a few things on my own





**Total time Spent: 30min(7:00pm to 7:30pm)**
